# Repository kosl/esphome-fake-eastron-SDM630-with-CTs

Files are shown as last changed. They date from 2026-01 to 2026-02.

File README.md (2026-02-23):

## ESPHome Fake Eastron SDM630 Modbus v2 with CTs
[][commits]
[][commits]
[](https://github.com/esphome)

This project [kosl/esphome-fake-eastron-SDM630-with-CTs](https://github.com/kosl/esphome-fake-eastron-SDM630-with-CTs) allows you to provide live data from current transformers (CTs) to a solar inverter that expects an [Eastron SDM630](https://www.eastroneurope.com/products/view/sdm630modbus).

Such example is Deye inverter

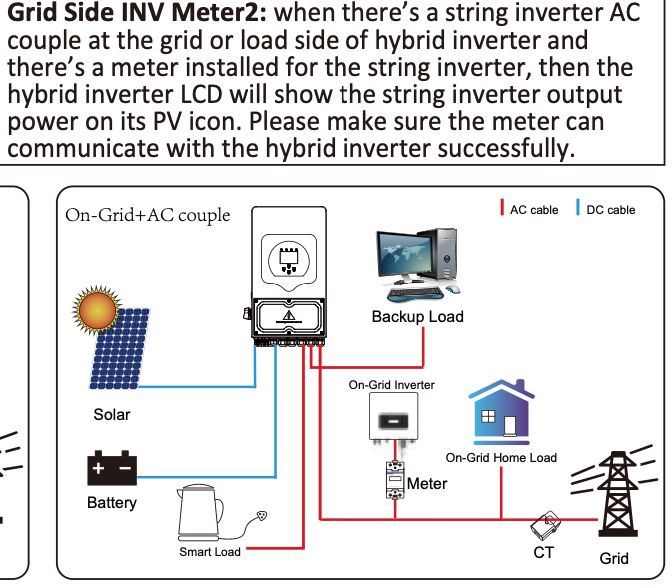
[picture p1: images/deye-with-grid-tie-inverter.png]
Grid-tie inverter


We will use ESP32-C3 SuperMini board with addition of "external" CTs and few resistors as shown below 

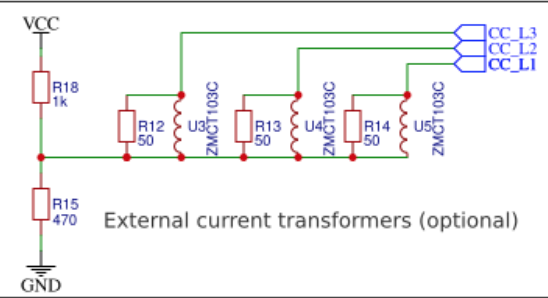
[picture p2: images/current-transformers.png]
CTsr


Since this will be installed in SUN-12K-SG04LP3 inverter we will also 
add local [Modbus dongle](https://github.com/rosenrot00/esphome_modbus_bridge)  
for use in [Solarman](https://github.com/davidrapan/ha-solarman) integration.

## How is this working?

The project provides an ESPhome component acting as a server that can be polled by a master (e.g. a solar inverter) via Modbus RTU. It behaves as much as possible like the Eastron SDM630 while fetching the actual data from the CTs.

### How exactly?

* On boot, the ESPhome starts a Modbus slave on address 2. This is where Deye expects to find the vanilla Eastron SDM630 Modbus V2. It registers several input registers that can be queried by a Modbus master (Deye inverter).
* At 1.7s intervals, it makes a request to CTs fetching live data.
* CT values are parsed and converted to IEEE-754 float and written to the matching registers.
* Voltages for each phase can be calibrated from Deye inverter through Modbus or by Home Assistant integration.
* The inverter queries the Modbus slave several times a second, fetching the input registers in various groups.
* Alternatively, the power mappings for Deye (through emulated SDM630 meter) can be provided directly from the inverter. In this example this is Solaredge 17K with external utility meter that can also be used as a meter for "EX_MeterCT" input.

The "Total solar power" displayed at Deye inverter is now a sum of DC Power PV1 and AC_Solar (PhaseA + PhaseB + PhaseC).

    Total solar power = DC Power PV1 + AC_Solar PhaseA + AC_Solar PhaseB + AC_Solar PhaseC

## Why?

I use a SUN-12K-SG04LP3-EU hybrid inverter. The inverter only supports two types of smart meters, which must be connected via RS485:

* Eastron SDM630 Modbus V2 or V3
* CHINT DTSU666 smart meter 

In my case the inverter is installed less than 15m from the grid connection. 

Since the ESP32-C3 is very cheap this simple ESPhome project bridges manufacturer, distance, physical layer and protocol.

## Implementation
For implementation the cheapest ESP32-C3 Super Mini module (€2.5-€4), some resistors, and RS485 to TTL module(s) are required.
Compete cost is under €10 excluding costs of CTs that can be various (cheap, split-core, different ratios, accuracy,...)

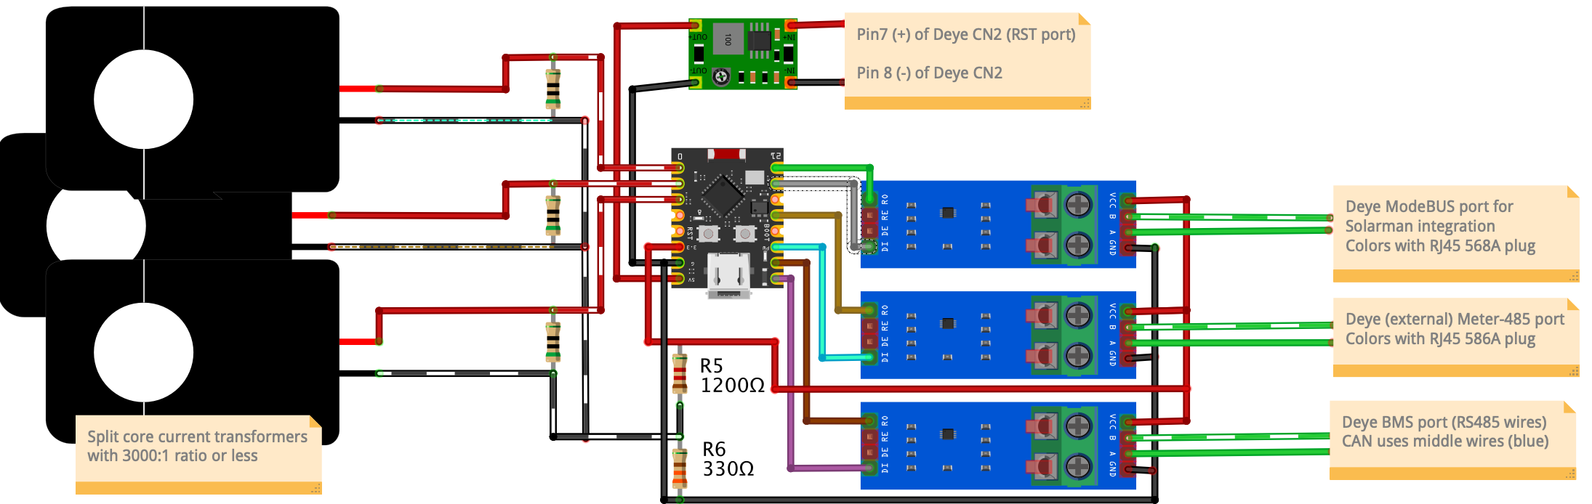
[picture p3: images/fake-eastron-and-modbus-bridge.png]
Fake Eastron


### Burden resistor

ESP32-C3 at 6dB attenuation can measure up to 1350 mV. Middle voltage is 675 mV.
If having CT with ratio 1:3000 that at 35A primary one gets 0.01167 A at secondary. 
Burden resistor should not be larger than R_max = 0.675/0.01167 = 57 Ohm.
Therefore we select R = 47 Ohm that is somewhat compatible with UTP cable.

For getting middle voltage 0.675 V from 3.3 V divisor by selecting lower R6 at 330Ω 
the upper R5 is (3.3-0.675)/(0.675/330)=1283Ω and therefore we select 1K2 resistor. 

## Installation

1. Connect ESP32 dev board to RS485 module.
2. Connect RS485 A and B connectors to pins 5 (A) and 4 (B) of the Deye RJ45 Port for RS 485.
3. Build and flash the firmware based on the [sample ESPhome config](./fake-eastron.yaml).
4. Calibrate ADCs to correspond Deye CTs readings. For this CTs should be placed in serial with Deye CTs and both should show the same currents on all phases.
5. Enable meter-reading in Deye as explained in the following examples.

All 4 modules (ESP32-S3, stepdown regulator below, and RS485 module stacked) 
with resistors for the CTs bridge shown below.
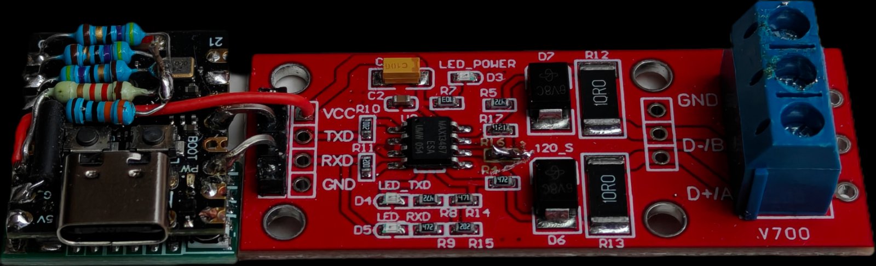
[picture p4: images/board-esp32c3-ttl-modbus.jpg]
Board

Note that some RS485 modules have TXD and RXD marked reversed (`tx_pin` is connected to TXD) as shown in the folowing photo.
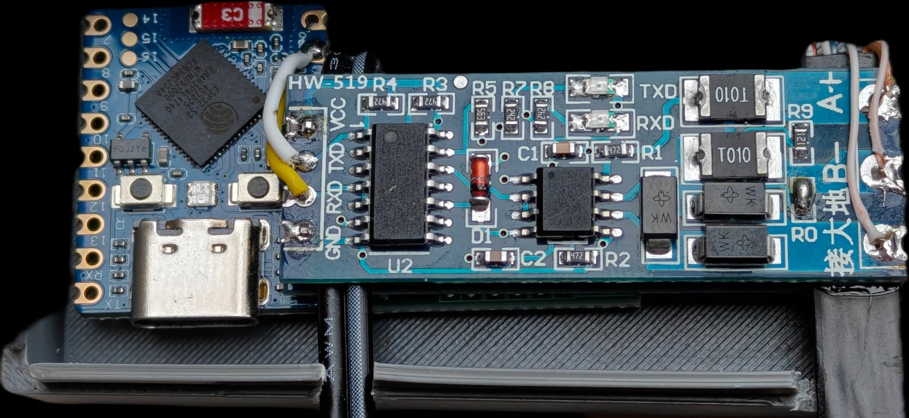
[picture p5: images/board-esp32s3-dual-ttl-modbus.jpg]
Board


When more virtual Modbus devices are needed then ESP32-S3 zero is recommended that has 3 UARTS and can host Solaredge Modbus/TCP client fetching directly from the inverter or Modbus/RTU for direct Solaredge coupling. In the following photo all 3 RS485 modules are stacked on on top of each other with voltage converter and ESP32S3 zero where everything packs inside single 3D printed box.
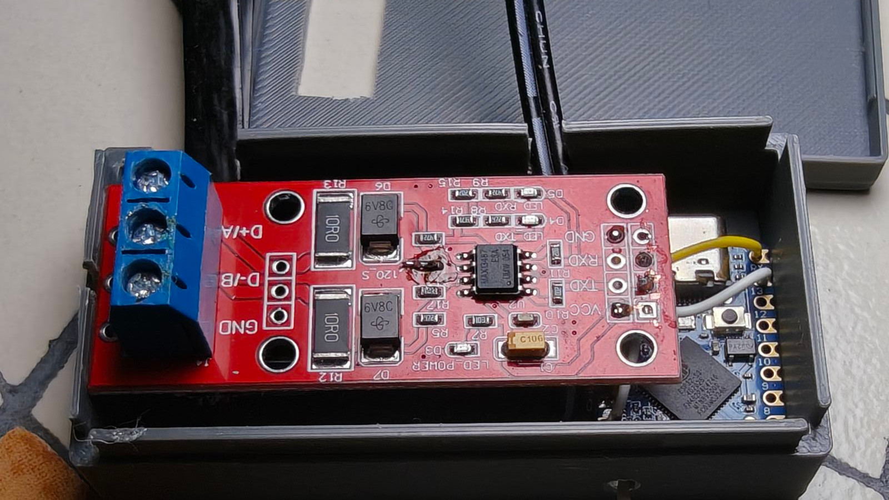
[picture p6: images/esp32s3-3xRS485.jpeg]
Board3


Final Deye SUN 12K-SG04LP3 installation is shown in the photo below. Antenna from ESP32S3 zero is 31 mm wire extending through box and inverter.
Board3
For long signal trains it is advisable to add ferite ring around to prevent EMI events.

### Modbus device address and registers

Deye expects different smart meters at different slave addresses:

| Meter | Phases | Slave address | Register addresses | 
|---|---|---|---|
| Eastron SDM630 v2 | 3 | 1 | 0x0C, 0x0E, 0x10, 0x48, 0x4A |
| Eastron SDM630 v2 | 3 | 2 | 0x0C, 0x0E, 0x10, 0x12 |

Poling frequency depends on the meters enabled under "Advanced Function-1" in Deye "Professional settings".
| Address | Registers | MeterCT | Meter2  | Dual Meter |  Meaning of registers |
|---|---|---|---|---|---|
| 1 | 0x0C, 0x0E, 0x10 | 7.23 Hz | 3 Hz | 6.6 Hz | 3 Phase Power registers |
| 1 | 0x48, 0x4A | 0.66 Hz | 0.27 Hz | 0.6 Hz | Energy Import/Export |
| 2 | 0x0C, 0x0E, 0x10, 0x12  | 0 Hz | 0.27 Hz | 0.6 Hz | 3 x Power Real and 1 x Apparent (VA) |

The fastest readings are if only external MeterCT is enabled. Then no `Grid Tie Meter2` readings are requested. 

The "Grid Tie Meter2:" expects "Eastron" slave at address 0x02. 

If "Grid Tie Meter2" is enabled then external utility meter is tried at address 0x01 in any case. If `EX_MeterCT:` is disabled the reading is tried 12 times anyway (6 times 0x0C, 0x0E, 0x10, then once 0x48, 0x4A and again 5 times x0C, 0x0E, 0x10). The readings without dual meter (just Meter2) are slower than with "Dual Meter" due to timeouts on address 0x01 with no MeterCT responses.

Requests in `Ex_MeterCT` are issued for 3 Phase Power registers (0x000C, 0x000E, 0x0010) and energy registers 0x0048 "Import Wh since last reset" with 0x004A "Export Wh since last reset". The same frequency as for energy registers is used for Meter2 registers 0x0C, 0x0E, 0x10, 0x12. Other registers are not queried from the meters, leaving a small subset of register needed to query and provide for Deye's operation.

When providing Ex_MeterCT reading from other sources (e.g. Solaredge Inverter) via Modbus it is important to note that the 6 Hz frequency is required for Peak shaving functionality where CT reading are in the interter's control loop. Providing meter reading with lower frequency introduces inverter instability that is demostrated as large oscilations around peak shaving power. It is therefore recommended that slow `EX_MeterCT` are not enabled but still provided (as fake meter at addres 0x01) in order to have faster reading as "dual meter", while Deye's CTs are used for utility meter and "Grid Tie Meter2" is queried at 0.6 Hz (every 1.5 s).

The communication speed for reading Solaredge can be low (19200 baud) due to asynchronous nature of Esphome Modbus operation and hardware UART support. MOr problems on the high update rate can cause many sensors published. For that reason the number of published sensors from the Solaredge is kept low where only necessary sensors are updated through shared global variables. Since "EX_MeterCT" is only of informational nature in the "Grid Tie Meter2" loop update it can be updated from Solaredge sparsly while still providing high server rates at address 0x01. 

### Module configurations

There are several examples listed below that are being tested and implmented until final solution with ESP32-S3 zero and 3xRS485 was finalized.

1. [deye-bridge.yaml](deye-bridge.yaml) - Solaredge Modbus/TCP to Eastron SDM630 with Modbus/TCP->RTU bridge for HA-Solarman
2. [example-modbus-server.yaml](example-modbus-server.yaml) Testing two TTL-Modbus/RTU modules in client/server (master/slave) coupling.
3. [modbus-bridge.yaml](modbus-bridge.yaml) Testing Modbus TCP to RTU bridge.
4. [deye-esphome.yaml](deye-esphome.yaml) Testing Modbus port on Deye SUN-12K SG04LP3
5. [fake-eastron-example.yaml](fake-eastron-example.yaml) Example of Eastron with CTs for Deye Meter2 (incomplete). Mapping for voltage can be fixed (230 V) or can be provided from source such as Deye or other inverter.
6. [solarege-to-eastron-example.yaml](solarege-to-eastron-example.yaml) Energy meter example that has two RS485 modules to verify communication from SolarEdge inverter that translates to fake SDM630 meter acting as a slave (server). Another RS485 uses standard ESPHome SDM meter component to read as a master (client) the data provided from fake SDM630 meter.
7. [solaredge-modbus-rtu.yaml](solaredge-modbus-rtu.yaml] Solaredge logger as Modbus RTU master.
8. [deye-with-solaredge-rtu.yaml](deye-with-solaredge-rtu.yaml) Solaredge Modbus/RTU to Eastron SDM630 with Modbus/TCP->RTU bridge for HA-Solarman. See final photo.
9. [pace-bms-logger.yaml](deye-with-solaredge-rtu.yaml) PACE BMS logger as separate project with dual battery packs. 

## External documentation & tools
* [Eastron SDM630 Modbus Protocol](docs/SDM630-Modbus_Protocol.pdf)
* [Eastron modbus register maps for SDM120 to SDM630](https://www.aggsoft.com/modbus-data-logging/eastron.htm)
* [ESP32 NodeMCU pinout](docs/ESP-32_NodeMCU_Developmentboard_Pinout.pdf)
* [IEEE-754 Floating Point Converter](https://www.h-schmidt.net/FloatConverter/IEEE754.html)
* [Online Modbus Parse](https://rapidscada.net/modbus/)
* Python tool to query an Eastron; for testing/verification: [https://github.com/nmakel/sdm_modbus](https://github.com/nmakel/sdm_modbus)
* [ESPHome current clamp sensor](https://esphome.io/components/sensor/ct_clamp)
* [ESPHome ADC sensor](https://esphome.io/components/sensor/adc)
* [ESPHome for Deye](https://github.com/klatremis/esphome-for-deye)
* [ESP32-C3 Super Mini Plus](https://www.espboards.dev/esp32/esp32-c3-super-mini-plus/)
* [Modbus bridge for Solarman](https://github.com/rosenrot00/esphome_modbus_bridge)  
* [ESPHome PACE BMS](https://github.com/syssi/esphome-pace-bms/)

[releases-shield]: https://img.shields.io/github/v/release/kosl/esphome-fake-eastron-SDM630-with-CTs
[commits-shield]: https://img.shields.io/github/commit-activity/m/kosl/esphome-fake-eastron-SDM630-with-CTs
[last-commit-shield]: https://img.shields.io/github/last-commit/kosl/esphome-fake-eastron-SDM630-with-CTs
[platform-shield]: https://img.shields.io/badge/platform-ESPHome-blue

[releases]: https://github.com/kosl/esphome-fake-eastron-SDM630-with-CTs/releases
[commits]: https://github.com/kosl/esphome-fake-eastron-SDM630-with-CTs/commits/main

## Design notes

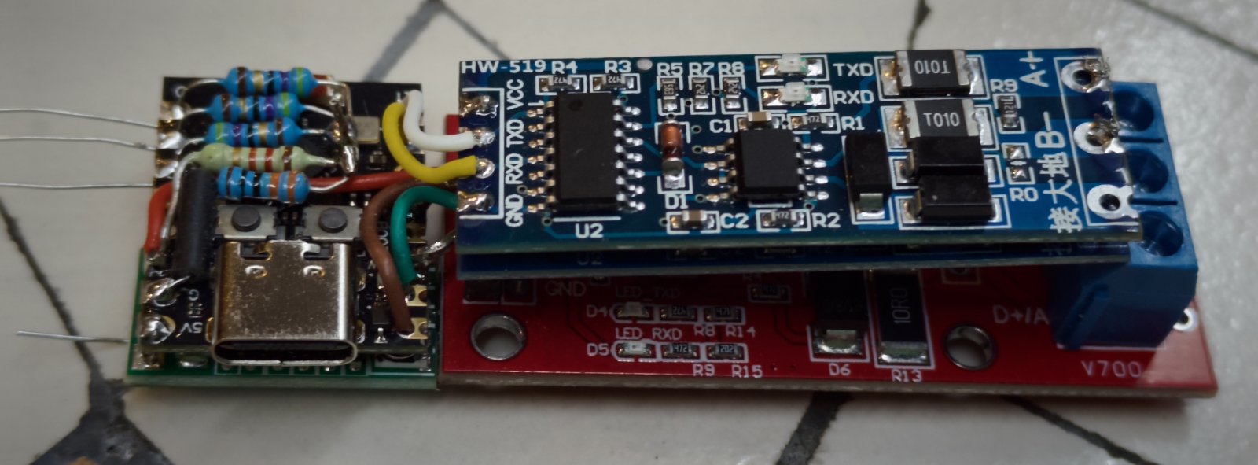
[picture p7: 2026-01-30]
images/board.jpeg

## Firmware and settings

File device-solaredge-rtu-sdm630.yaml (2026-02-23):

# This device provides Solaredge RTU readings as fake meters for Deye as two Eastron SDM630 meters. 

# https://knowledge-center.solaredge.com/sites/kc/files/sunspec-implementation-technical-note.pdf pp.15-17
# CPU Firmware 4.22.44 SolarEdge TCP timeout issue https://github.com/evcc-io/evcc/issues/25424 and https://www.solaredge.com/en/support/residential-inverters-firmware
#  0 40071 40072 1 I_AC_Current uint16 Amps AC Total Current value
#  1 40072 40073 1 I_AC_CurrentA uint16 Amps AC Phase A Current value
#  2 40073 40074 1 I_AC_CurrentB uint16 Amps AC Phase B Current value
#  3 40074 40075 1 I_AC_CurrentC uint16 Amps AC Phase C Current value
#  4 40075 40076 1 I_AC_Current_SF int16 AC Current scale factor
#  5 40076 40077 1 I_AC_VoltageAB uint16 Volts AC Voltage Phase AB value
#  6 40077 40078 1 I_AC_VoltageBC uint16 Volts AC Voltage Phase BC value
#  7 40078 40079 1 I_AC_VoltageCA uint16 Volts AC Voltage Phase CA value
#  8 40079 40080 1 I_AC_VoltageAN 1 uint16 Volts AC Voltage Phase A to N value
#  9 40080 40081 1 I_AC_VoltageBN 1 uint16 Volts AC Voltage Phase B to N value
# 10 40081 40082 1 I_AC_VoltageCN 1 uint16 Volts AC Voltage Phase C to N value
# 11 40082 40083 1 I_AC_Voltage_SF int16 AC Voltage scale factor
# 12 40083 40084 1 I_AC_Power int16 Watts AC Power value
# 13 40084 40085 1 I_AC_Power_SF int16 AC Power scale factor
# 14 40085 40086 1 I_AC_Frequency uint16 Hertz AC Frequency value
# 15 40086 40087 1 I_AC_Frequency_SF int16 Scale factor
# 16 40087 40088 1 I_AC_VA int16 VA Apparent Power
# 17 40088 40089 1 I_AC_VA_SF int16 Scale factor
# 18 40089 40090 1 I_AC_VAR2 int16 VAR Reactive Power
# 19 40090 40091 1 I_AC_VAR_SF2 int16 Scale factor
# 20 40091 40092 1 I_AC_PF1 int16 % Power Factor
# 21 40092 40093 1 I_AC_PF_SF1 int16 Scale factor
# 22 40093 40094 2 I_AC_Energy_WH acc32 WattHours AC Lifetime Energy production
# 23 40094 40095 
# 24 40095 40096 1 I_AC_Energy_WH_SF uint16 Scale factor
# 25 40096 40097 1 I_DC_Current uint16 Amps DC Current value
# 26 40097 40098 1 I_DC_Current_SF int16 Scale factor
# 27 40098 40099 1 I_DC_Voltage uint16 Volts DC Voltage value
# 28 40099 40100 1 I_DC_Voltage_SF int16 Scale factor
# 29 40100 40101 1 I_DC_Power int16 Watts DC Power value
# 30 40101 40102 1 I_DC_Power_SF int16 Scale factor
# 31 40103 40104 1 I_Temp_Sink int16 Degrees C Heat Sink Temperature
# 32 40106 40107 1 I_Temp_SF int16 Scale factor
# 33 40107 40108 1 I_Status uint16 Operating State

# Meter 1 pp.20-23
# Current
# 40190 40191 1 M_AC_Current int16 Amps AC Current (sum of active phases)
# 40191 40192 1 M_AC_Current_A int16 Amps Phase A AC Current
# 40192 40193 1 M_AC_Current_B int16 Amps Phase B AC Current
# 40193 40194 1 M_AC_Current_C int16 Amps Phase C AC Current
# 40194 40195 1 M_AC_Current_SF int16 SF AC Current Scale Factor
# Voltage
# Line to Neutral Voltage
# 40195 40196 1 M_AC_Voltage_L N int16 Volts Line to Neutral AC Voltage (average of active phases)
# 40196 40197 1 M_AC_Voltage_A N int16 Volts Phase A to Neutral AC Voltage
# 40197 40198 1 M_AC_Voltage_B N int16 Volts Phase B to Neutral AC Voltage
# 40198 40199 1 M_AC_Voltage_C N int16 Volts Phase C to Neutral AC Voltage
# Line to Line Voltage
# 40199 40200 1 M_AC_Voltage_LL int16 Volts Line to Line AC Voltage (average of active phases)
# 40200 40201 1 M_AC_Voltage_AB int16 Volts Phase A to Phase B AC Voltage
# 40201 40202 1 M_AC_Voltage_BC int16 Volts Phase B to Phase C AC Voltage
# 40202 40203 1 M_AC_Voltage_CA int16 Volts Phase C to Phase A AC Voltage
# 40203 40204 1 M_AC_Voltage_SF int16 SF AC Voltage Scale Factor 
# Frequency
# 40204 40205 1 M_AC_Freq int16 Herts AC Frequency
# 40205 40206 1 M_AC_Freq_SF int16 SF AC Frequency Scale Factor Power
# Real Power
# 40206 40207 1 M_AC_Power int16 Watts Total Real Power (sum of active phases)
# 40207 40208 1 M_AC_Power_A int16 Watts Phase A AC Real Power
# 40208 40209 1 M_AC_Power_B int16 Watts Phase B AC Real Power
# 40209 40210 1 M_AC_Power_C int16 Watts Phase C AC Real Power
# 40210 40211 1 M_AC_Power_SF int16 SF AC Real Power Scale Factor Apparent Power
# 40211 40212 1 M_AC_VA int16 Volt- Amps Total AC Apparent Power (sum of active phases)
# 40212 40213 1 M_AC_VA_A int16 Volt- Amps Phase A AC Apparent Power
# 40213 40214 1 M_AC_VA_B int16 Volt- Amps Phase B AC Apparent Power
# 40214 40215 1 M_AC_VA_C int16 Volt- Amps Phase C AC Apparent Power
# 40215 40216 1 M_AC_VA_SF int16 SF AC Apparent Power Scale Factor
# Reactive Power
# 40216 40217 1 M_AC_VAR int16 VAR Total AC Reactive Power (sum of active phases)
# 40217 40218 1 M_AC_VAR_A int16 VAR Phase A AC Reactive Power
# 40218 40219 1 M_AC_VAR_B int16 VAR Phase B AC Reactive Power
# 40219 40220 1 M_AC_VAR_C int16 VAR Phase C AC Reactive Power
# 40220 40221 1 M_AC_VAR_SF int16 SF AC Reactive Power Scale Factor
# Power Factor
# 40221 40222 1 M_AC_PF int16 % Average Power Factor (average of active phases)
# 40222 40223 1 M_AC_PF_A int16int16 % Phase A Power Factor
# 40223 40224 1 M_AC_PF_B int16 % Phase B Power Factor
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

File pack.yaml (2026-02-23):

# https://github.com/syssi/esphome-pace-bms/blob/main/multiple-batteries-example/pack.yaml
binary_sensor:
  - platform: modbus_controller
    modbus_controller_id: ${modbus_controller_id}
    device_id: ${device_id}
    name: "Charging Operation"
    address: 11
    register_type: holding
    bitmask: 0x0100

  #      Bit 9: Status: Discharging operation
  - platform: modbus_controller
    modbus_controller_id: ${modbus_controller_id}
    device_id: ${device_id}
    name: "Discharging Operation"
    address: 11
    register_type: holding
    bitmask: 0x0200

  #      Bit 10: Status: Charging enabled/disabled
  - platform: modbus_controller
    modbus_controller_id: ${modbus_controller_id}
    device_id: ${device_id}
    name: "Charging"
    address: 11
    register_type: holding
    bitmask: 0x0400

  #      Bit 11: Status: Discharging enabled/disabled
  - platform: modbus_controller
    modbus_controller_id: ${modbus_controller_id}
    device_id: ${device_id}
    name: "Discharging"
    address: 11
    register_type: holding
    bitmask: 0x0800

  #  12  Balance status-bits per cell (1-16)   2 byte   R  uint16  Hex
  #      Bit 1: Status: Balancing cell 1
  - platform: modbus_controller
    modbus_controller_id: ${modbus_controller_id}
    device_id: ${device_id}
    name: "Cell Balancing 1"
    address: 12
    register_type: holding
    bitmask: 0x0001

  #      Bit 2: Status: Balancing cell 2
  - platform: modbus_controller
    modbus_controller_id: ${modbus_controller_id}
    device_id: ${device_id}
    name: "Cell Balancing 2"
    address: 12
    register_type: holding
    bitmask: 0x0002

  #      Bit 3: Status: Balancing cell 3
  - platform: modbus_controller
    modbus_controller_id: ${modbus_controller_id}
    device_id: ${device_id}
    name: "Cell Balancing 3"
    address: 12
    register_type: holding
    bitmask: 0x0004

  #      Bit 4: Status: Balancing cell 4
  - platform: modbus_controller
    modbus_controller_id: ${modbus_controller_id}
    device_id: ${device_id}
    name: "Cell Balancing 4"
    address: 12
    register_type: holding
    bitmask: 0x0008

  #      Bit 5: Status: Balancing cell 5
  - platform: modbus_controller
    modbus_controller_id: ${modbus_controller_id}
    device_id: ${device_id}
    name: "Cell Balancing 5"
    address: 12
    register_type: holding
    bitmask: 0x0010

  #      Bit 6: Status: Balancing cell 6
  - platform: modbus_controller
    modbus_controller_id: ${modbus_controller_id}
    device_id: ${device_id}
    name: "Cell Balancing 6"
    address: 12
    register_type: holding
    bitmask: 0x0020

  #      Bit 7: Status: Balancing cell 7
  - platform: modbus_controller
    modbus_controller_id: ${modbus_controller_id}
    device_id: ${device_id}
    name: "Cell Balancing 7"
    address: 12
    register_type: holding
    bitmask: 0x0040

  #      Bit 8: Status: Balancing cell 8
  - platform: modbus_controller
    modbus_controller_id: ${modbus_controller_id}
    device_id: ${device_id}
    name: "Cell Balancing 8"
    address: 12
    register_type: holding
    bitmask: 0x0080

  #      Bit 9: Status: Balancing cell 9
  - platform: modbus_controller
    modbus_controller_id: ${modbus_controller_id}
    device_id: ${device_id}
    name: "Cell Balancing 9"
    address: 12
    register_type: holding
    bitmask: 0x0100

  #      Bit 10: Status: Balancing cell 10
  - platform: modbus_controller
    modbus_controller_id: ${modbus_controller_id}
    device_id: ${device_id}
    name: "Cell Balancing 10"
    address: 12
    register_type: holding
    bitmask: 0x0200

  #      Bit 11: Status: Balancing cell 11
  - platform: modbus_controller
    modbus_controller_id: ${modbus_controller_id}
    device_id: ${device_id}
    name: "Cell Balancing 11"
    address: 12
    register_type: holding
    bitmask: 0x0400

  #      Bit 12: Status: Balancing cell 12
  - platform: modbus_controller
    modbus_controller_id: ${modbus_controller_id}
    device_id: ${device_id}
    name: "Cell Balancing 12"
    address: 12
    register_type: holding
    bitmask: 0x0800

  #      Bit 13: Status: Balancing cell 13
  - platform: modbus_controller
    modbus_controller_id: ${modbus_controller_id}
    device_id: ${device_id}
    name: "Cell Balancing 13"
    address: 12
    register_type: holding
    bitmask: 0x1000

  #      Bit 14: Status: Balancing cell 14
  - platform: modbus_controller
    modbus_controller_id: ${modbus_controller_id}
    device_id: ${device_id}
    name: "Cell Balancing 14"
    address: 12
    register_type: holding
    bitmask: 0x2000

  #      Bit 15: Status: Balancing cell 15
  - platform: modbus_controller
    modbus_controller_id: ${modbus_controller_id}
    device_id: ${device_id}
    name: "Cell Balancing 15"
    address: 12
    register_type: holding
    bitmask: 0x4000
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

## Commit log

2026-01-25 Add breadboard
    [fake-eastron-and-modbus-bridge.fzz]
2026-01-25 Correct wiring for ports
    [fake-eastron-and-modbus-bridge.fzz]
2026-01-25 Create sub-devices for bridges
2026-01-30 Add prototype board
    [fake-eastron-and-modbus-bridge.fzz]
2026-02-01 Update README with RS485 module info and links
    Added note about RS485 module pin connections and included a link to Eastron modbus register maps.
2026-02-04 Solaredge on ESP32C3
2026-02-04 Example for ESP32-C3 supermini and ESP32-S3 zero
2026-02-11 Updated boards.
2026-02-11 Update README with implementation details and corrections
    Corrected the number of modules and clarified implementation details for the ESP32-C3 project. Added information about Modbus addresses and requests for the Grid Tie Meter2.
2026-02-11 Convert to ESP32-S3 zero board
2026-02-12 Update README with power mappings and total solar power details
    Added information about power mappings and total solar power calculation.
2026-02-12 Adjust request frequencies in README.md
    Updated request frequencies for 3 Phase Power and energy registers in the README.
